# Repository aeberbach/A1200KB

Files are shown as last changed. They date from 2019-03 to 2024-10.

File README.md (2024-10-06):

# A1200KB Mechanical keyboard for Amiga A1200

As of right now this is revision 4. I know it could be improved very, very slightly by changing the position of key groups by less than a millimetre but I think it's complete now. 

This PCB design was reverse-engineered from the original keyboard in an Amiga 1200. It is designed to connect to your Amiga 1200 with no modifications to the original machine, just take out the original keyboard and store it away safely. If you want an A600 keyboard, see my other repositories.

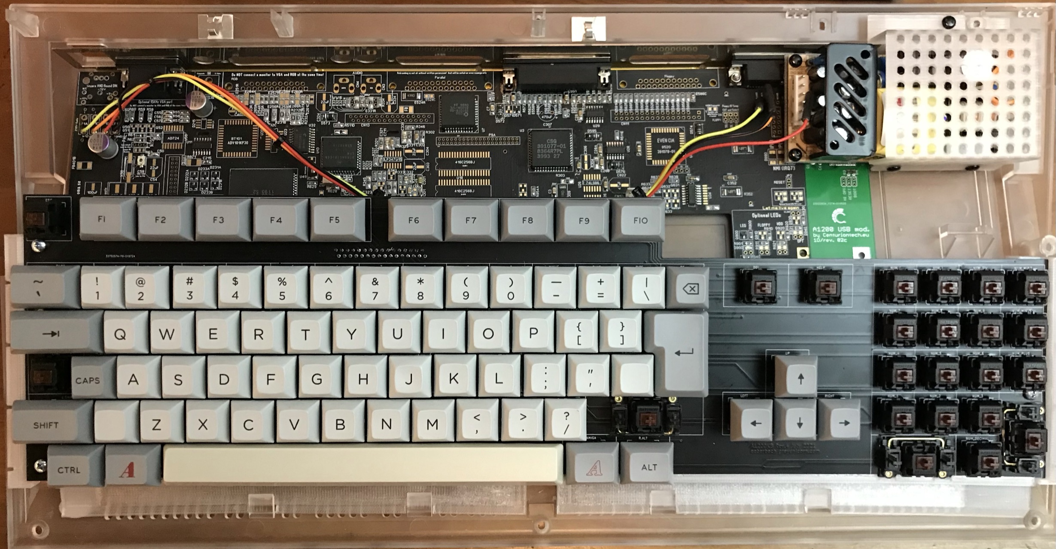
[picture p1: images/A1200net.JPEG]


The A1200.net case (with internal PSU and partially-completed [ReAmiga](http://www.reamiga.info/) board)

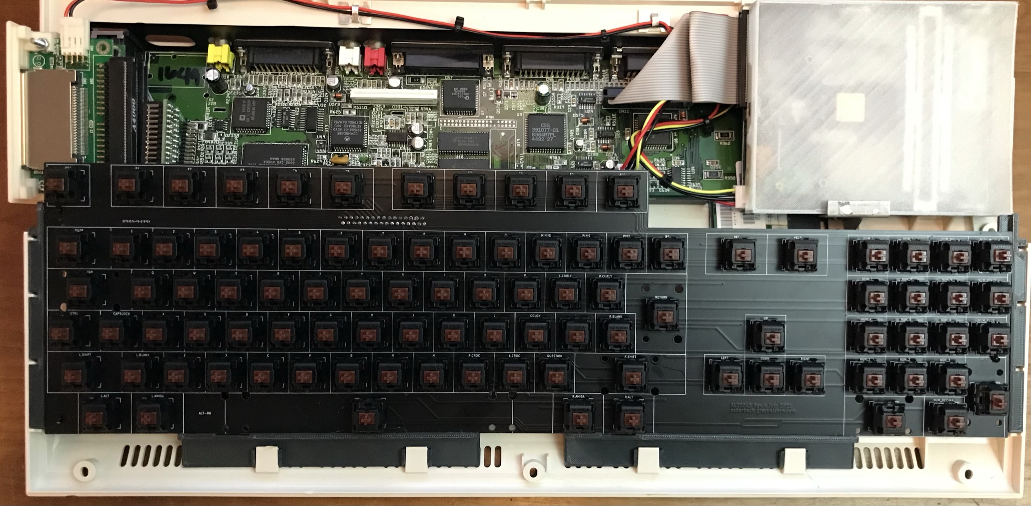
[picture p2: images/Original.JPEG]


The original Amiga case (with CF disk system and transparent floppy cover)

## Requirements
To make a working keyboard for your Amiga 1200, you need:

- one PCB (this project)
- 96 pieces MX-compatible PCB-mount (5-pin) keyswitch
- one LED (caps lock)
- one FFC connector, 32-way RA 1.25mm pitch. Molex 52044-3245 is one example, available from Mouser Electronics.
- one FFC ribbon cable, 32-way, 1.25mm pitch. Molex 15168-0400 is one example, available from Mouser Electronics.
- keycaps
- some way to mount the keyboard inside the Amiga (3D print some brackets from the STL folder...)
 
## Design
The Amiga 1200 keyboard is a simple passive key matrix connected via a 31-conductor cable. Some special keys are not on the matrix but have a dedicated circuit, such as the CTRL and Amiga keys - this is why so many conductors are necessary. The original Amiga 1200 PCB uses a 31-way FFC connector, I was not able to buy this anywhere as they are long discontinued. However cutting one conductor away from the cable allows it to fit in the Amiga connector with 31 conductors and to the keyboard with 32 conductors and everything is fine. The specified FFC cable is slightly longer than required but in 2019 there is not  a lot of choice available, so the longer one will do. 
I had my boards made with 1.6mm PCB substrate as any other thickness gets disproportionally expensive, no other special options. Using a piece of aluminium rail, 10x3mm, will make it as stiff as a keyboard should be while maintaining enough space underneath for an accelerator or Indivision etc. This is supported either side by the 3D printed mounts. Cover the aluminium with some kapton or other insulation if you have other internal components that may come dangerously close but in a stock Amiga there is plenty of clearance.

### Amiga Keycaps
These aren't widely available. I've tried making some using a blank set of keycaps from aliexpress and a laser etcher, but I do not know of anywhere that sells a MX-stem set of Amiga keycaps. I am using a 9U space bar but you can just as easily use 7U. If gaps either side of the space bother you, 3D print something to fill the space.

If you want a perfect set of keys, visit pimpmykeyboard.com - it will not be cheap but if you look hard enough you will find every key, even the Amiga keys, and you can have any legend printed on any size keycap so it is possible to make a perfect set. It will not be cheap. You can se a partial sample in the A1200.net picture. I am currently waiting for the extra numpad keys to arrive to complete this keyboard.

## Construction
Without going into all the detail here - as there is lots of detail on www.grayunicorn.com - I rate this a mid-level project. There is no power, no delicate soldering, and nothing can really be inserted the wrong way. Mounting the keyboard requires 3D printing the files you will find in the 3Dfiles folder.

If you have a replacement case produced by A1200.net then pick that folder, else the other folder. I don't know about cases made by ESCOM but I don't think they are at all different from the Commodore cases. I printed these in PETG, 0.4mm nozzle, 0.2mm layer height, supports are necessary. Mounting the keyboard with these designs allows the use of an accelerator card with a thick SIMM; I may design alternates if I get a slimmer accelerator, bringing the keys further back into the case but there is not much room.
 
You can damage your Amiga if you don't know what you are doing. Please be careful and if you are not experienced in projects like this get some help, maybe vist your local makerspace, and don't hurt yourself or your computer.

## Share
Most of all - if you have any suggestions for improvements, adding an issue or a pull request to this repo would be much appreciated. And share your project with the Amiga community, I'd really like to see what you made.

#### Donate?
I hate to think what this has cost so far. It's been fun and I'd do it again, but if you'd like to help the next project happen that would be awesome.



Note this this project is licensed under CC BY-NC-SA 4.0 - only noncommercial use is permitted! (By all means sell the excess PCBs you get, at cost, if you order some for your own use)

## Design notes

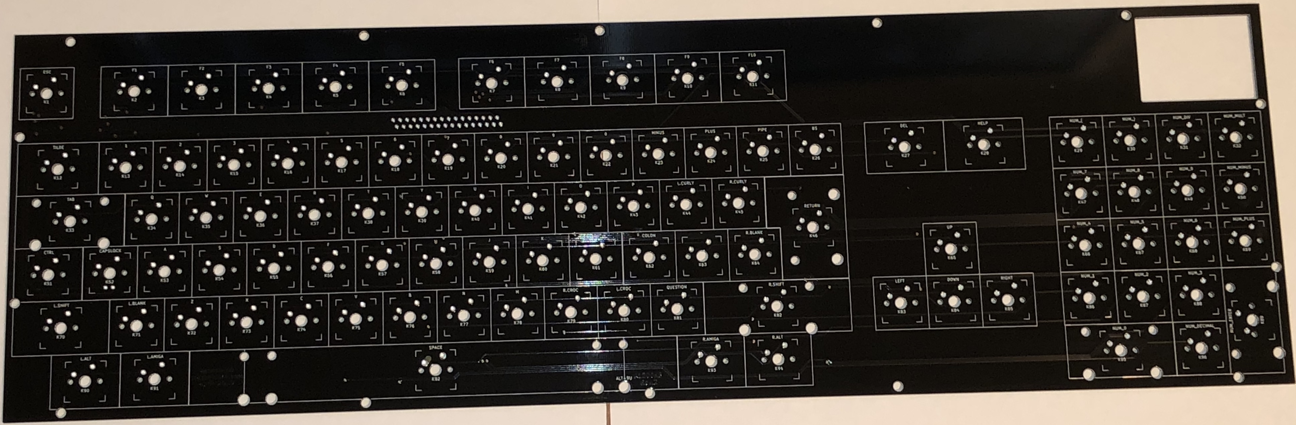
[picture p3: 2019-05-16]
images/rev2-pcb.jpg

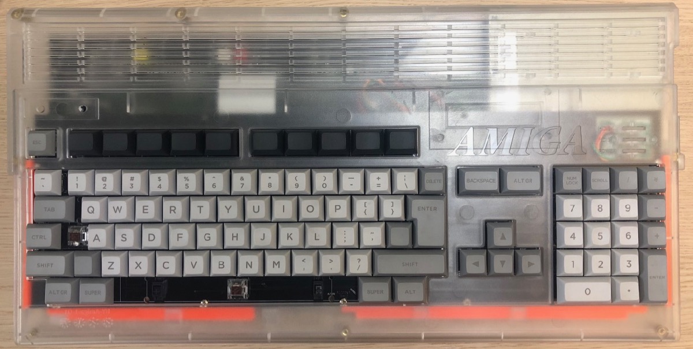
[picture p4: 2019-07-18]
images/case-closed.jpg

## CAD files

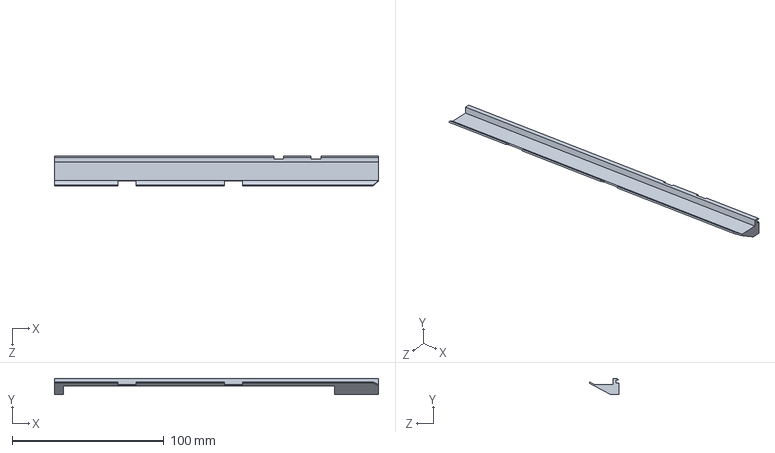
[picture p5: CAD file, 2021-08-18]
3Dfiles/A1200.net case/rev4/Right base.SLDPRT
213.5 x 10.6 x 19.5 mm

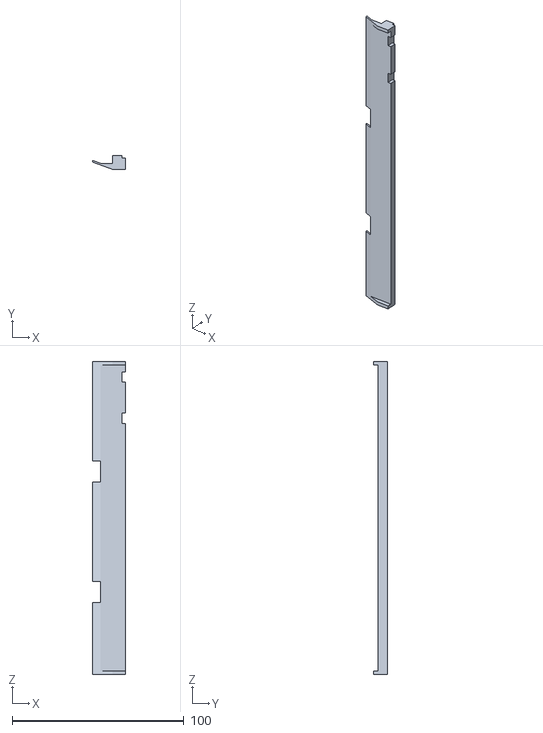
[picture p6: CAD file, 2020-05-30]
3Dfiles/A1200.net case/Right base support.stl
19.2 x 8.05 x 182.0

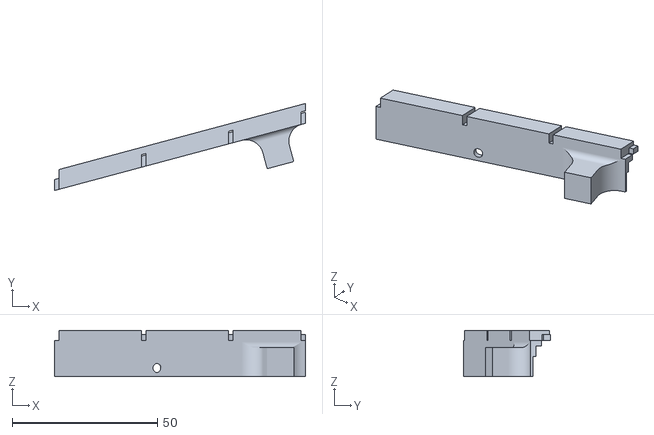
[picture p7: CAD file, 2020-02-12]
3Dfiles/Original Amiga case/Keyboard support right r2.stl
86.5 x 30.0 x 16.0

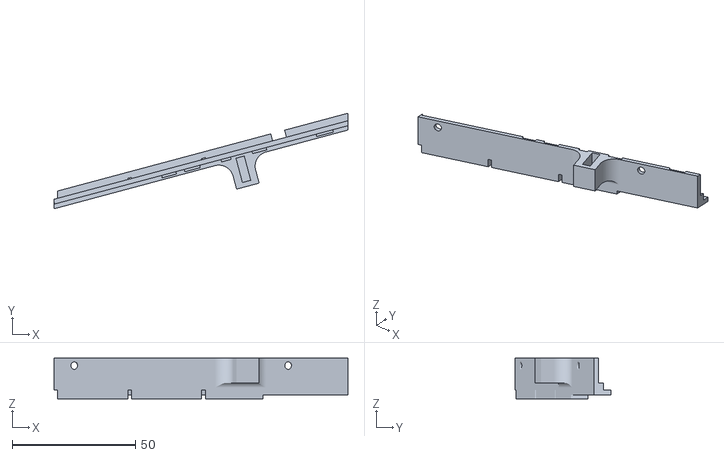
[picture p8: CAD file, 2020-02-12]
3Dfiles/Original Amiga case/rev2+3/Keyboard support left r2.stl
119.5 x 38.9 x 16.5

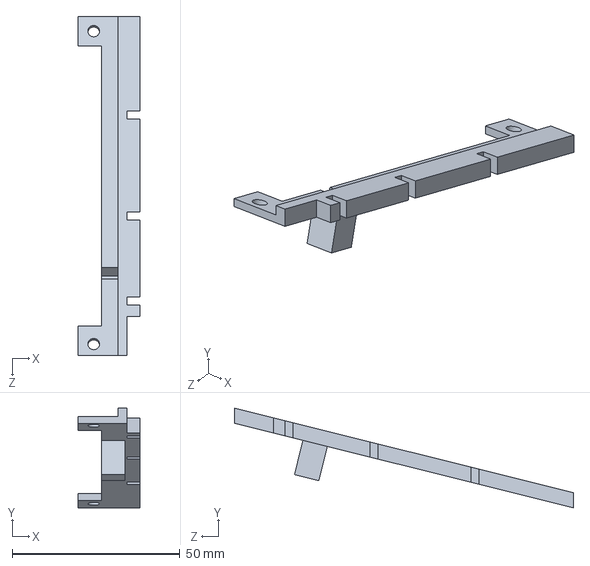
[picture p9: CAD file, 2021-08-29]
3Dfiles/Original Amiga case/rev4/Left side.SLDPRT
18.6 x 29.7 x 100.9 mm

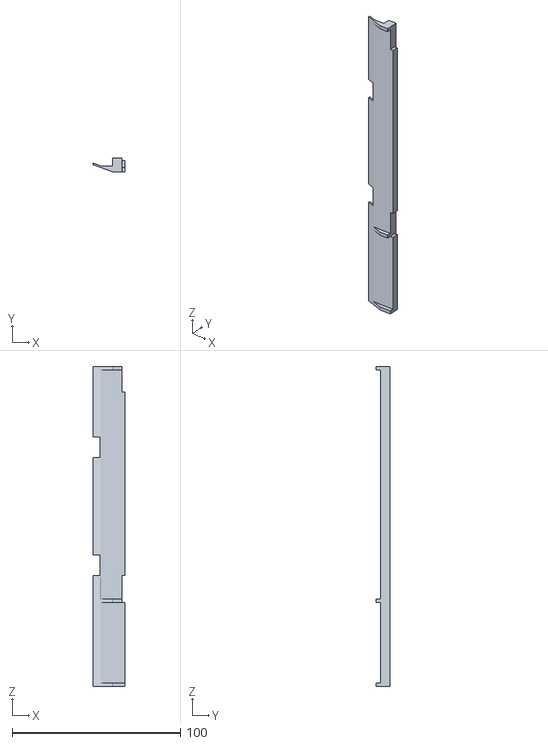
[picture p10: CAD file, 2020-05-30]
3Dfiles/A1200.net case/Left base support.stl
19.2 x 8.05 x 190.0

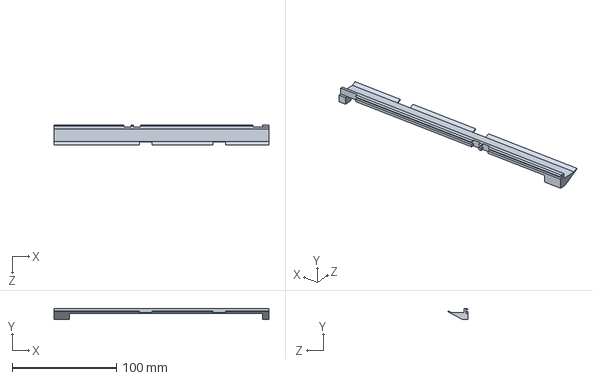
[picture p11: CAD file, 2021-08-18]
3Dfiles/A1200.net case/rev4/Left base.SLDPRT
206.0 x 10.6 x 19.5 mm

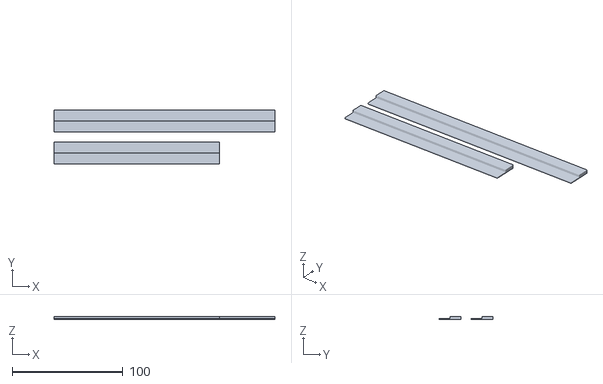
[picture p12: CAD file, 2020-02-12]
3Dfiles/Original Amiga case/kb base.stl
200.0 x 49.0 x 3.00

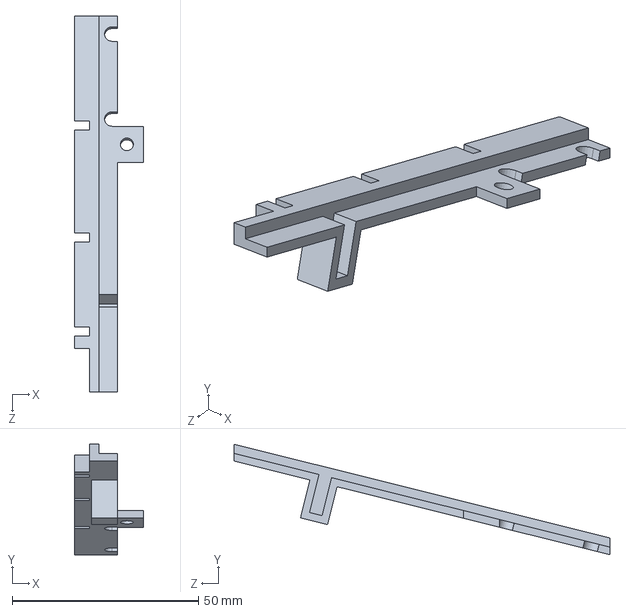
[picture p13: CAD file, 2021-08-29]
3Dfiles/Original Amiga case/rev4/Right side.SLDPRT
18.6 x 29.7 x 100.9 mm

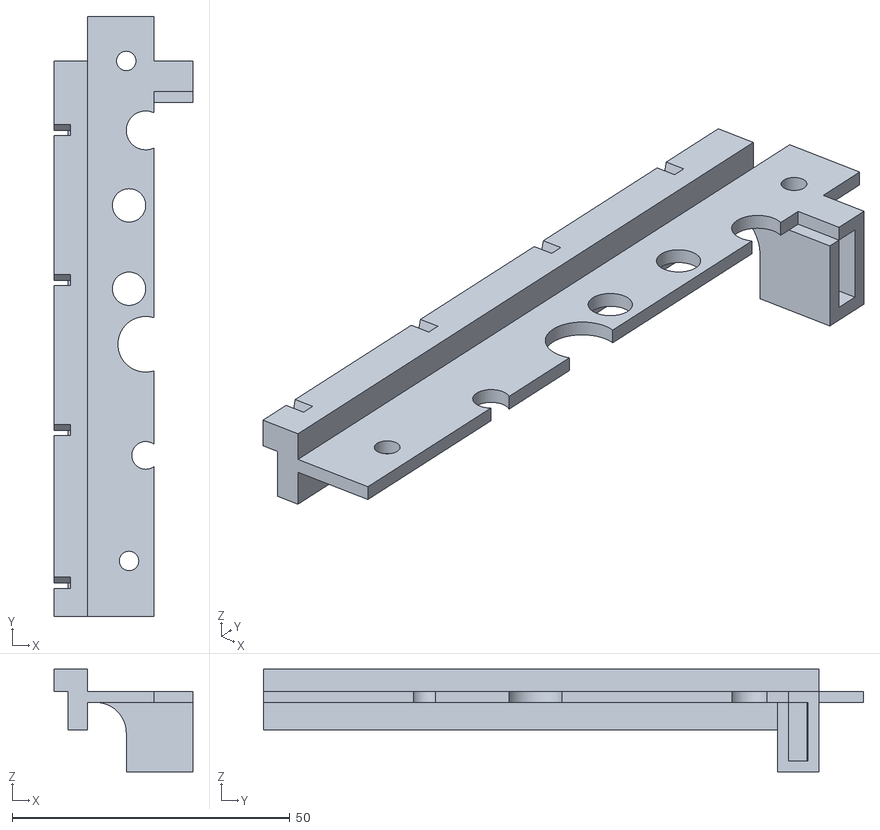
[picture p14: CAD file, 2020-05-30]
3Dfiles/A1200.net case/Left side.stl
25.0 x 108.0 x 18.5

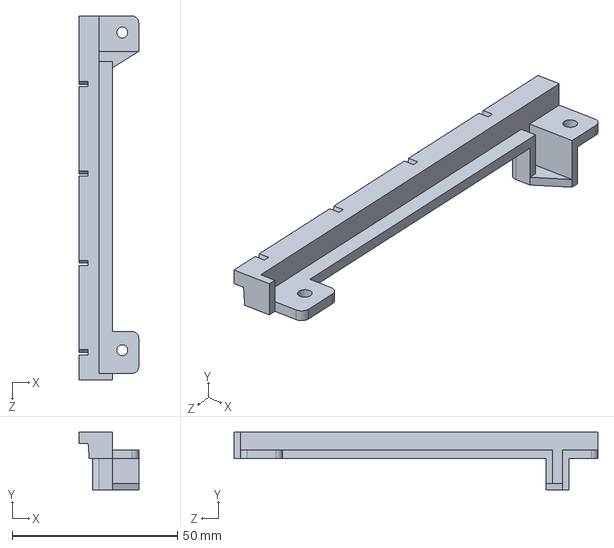
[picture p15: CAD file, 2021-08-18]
3Dfiles/A1200.net case/rev4/Left side.SLDPRT
18.0 x 17.5 x 110.0 mm

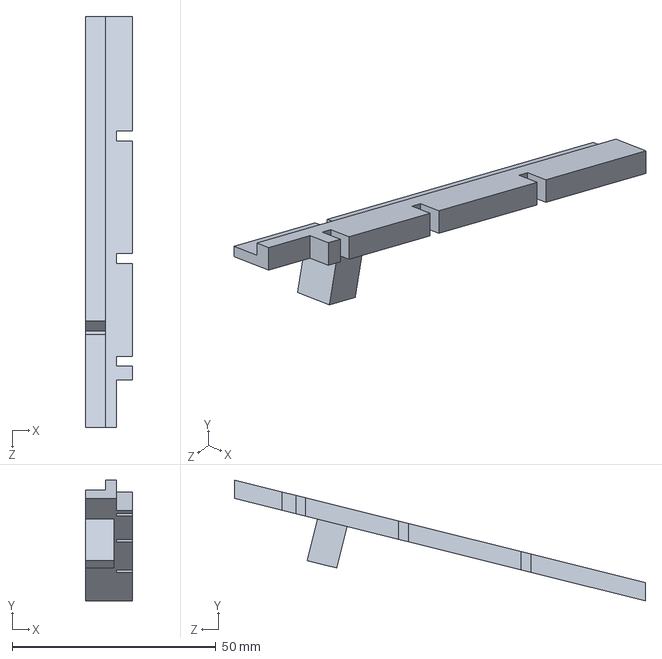
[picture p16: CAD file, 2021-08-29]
3Dfiles/Original Amiga case/rev4/Left side (for mirror).SLDPRT
11.6 x 29.7 x 100.9 mm

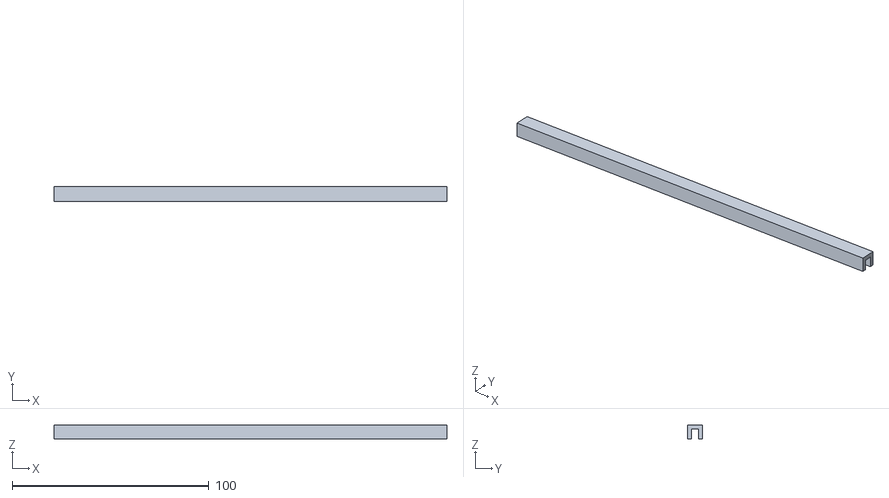
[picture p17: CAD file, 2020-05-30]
3Dfiles/A1200.net case/Brace insulator and spacer.stl
200.0 x 7.50 x 7.00

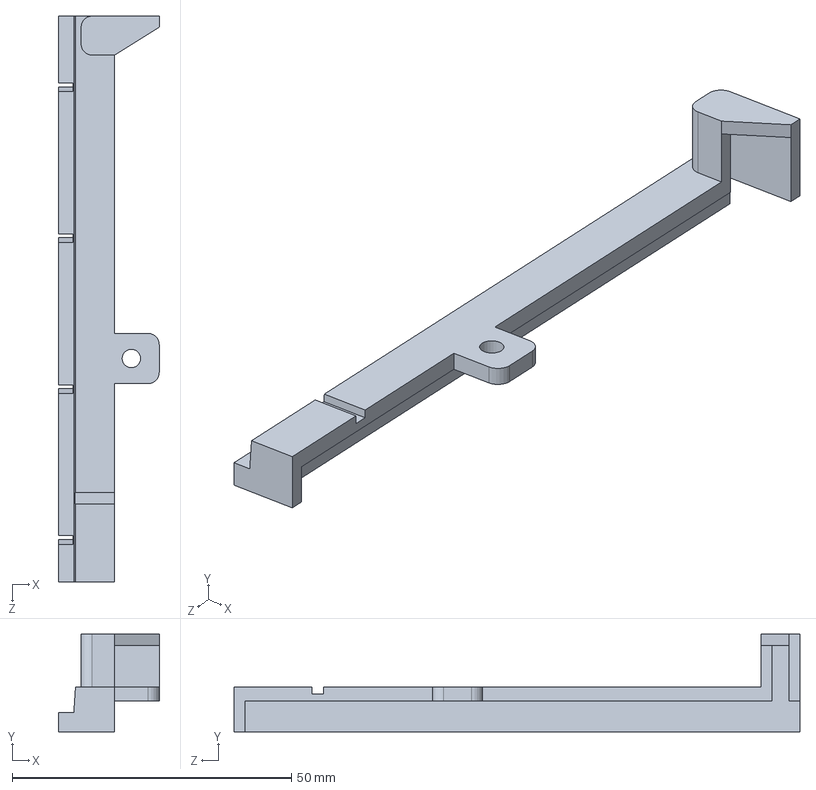
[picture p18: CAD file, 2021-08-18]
3Dfiles/A1200.net case/rev4/Right side.SLDPRT
18.0 x 17.5 x 101.3 mm

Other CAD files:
3Dfiles/Original Amiga case/rev4/Base.SLDPRT
3Dfiles/A1200.net case/Right side.stl
3Dfiles/A1200.net case/rev3/Right side.stl
3Dfiles/A1200.net case/rev4/Left base.STL
3Dfiles/A1200.net case/rev4/Left side.STL
3Dfiles/A1200.net case/rev4/Right base.STL
3Dfiles/A1200.net case/rev4/Right side.STL
3Dfiles/Original Amiga case/rev4/Base.STL
3Dfiles/Original Amiga case/rev4/Left side.STL
3Dfiles/Original Amiga case/rev4/Left side/Left side.ipt
3Dfiles/Original Amiga case/rev4/Right side.STL

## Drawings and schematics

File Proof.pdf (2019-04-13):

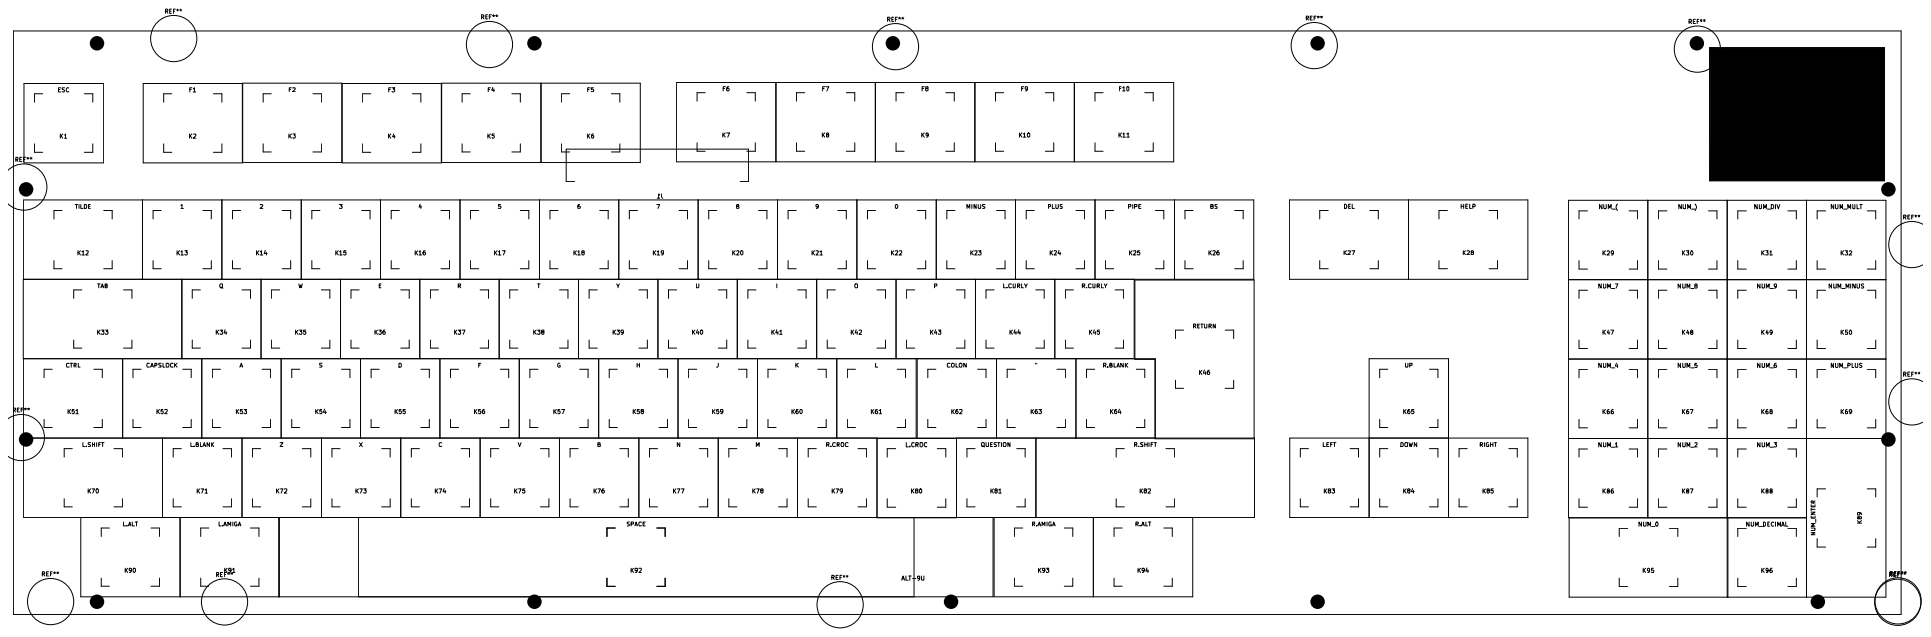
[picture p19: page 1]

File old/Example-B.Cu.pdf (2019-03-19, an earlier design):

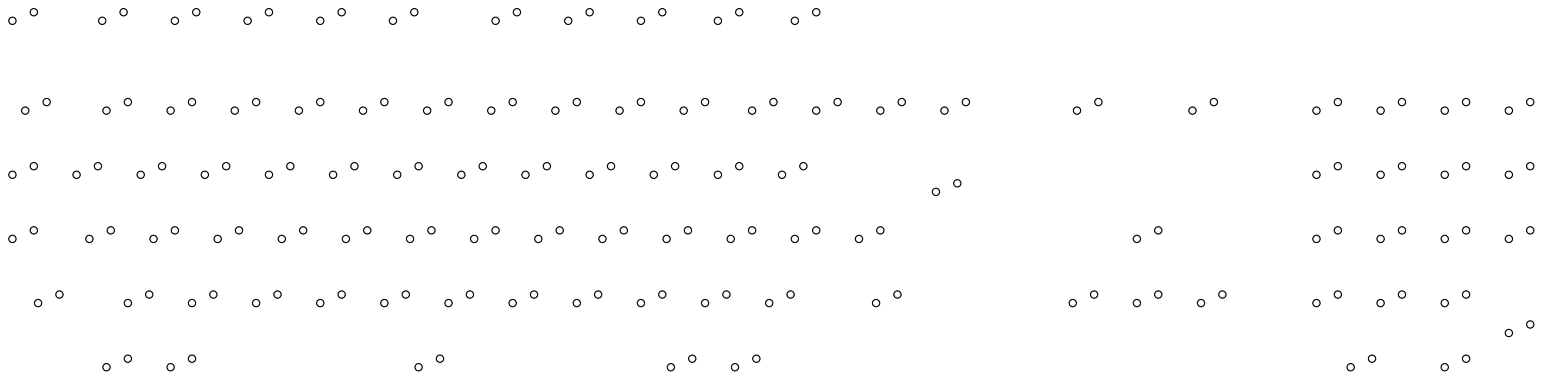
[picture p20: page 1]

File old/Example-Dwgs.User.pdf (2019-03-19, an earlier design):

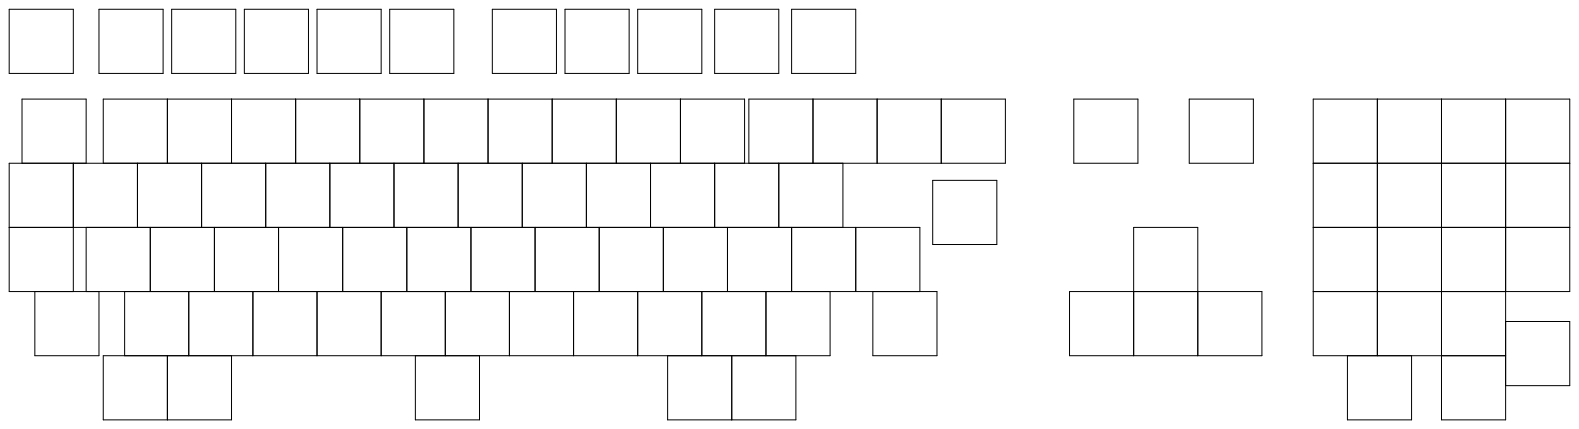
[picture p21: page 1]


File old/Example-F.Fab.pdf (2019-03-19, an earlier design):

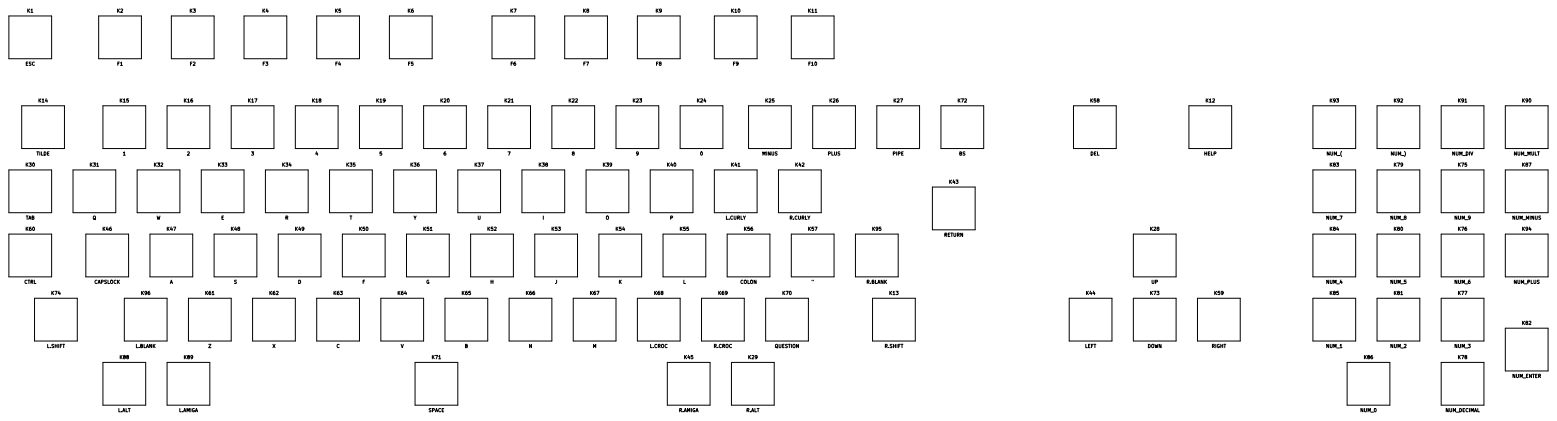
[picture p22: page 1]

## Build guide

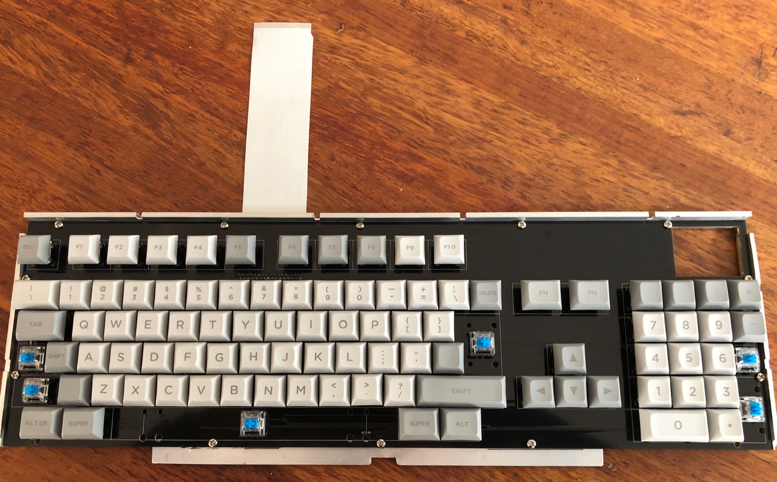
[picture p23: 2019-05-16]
images/soldered.jpg

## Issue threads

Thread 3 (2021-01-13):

Error Message when loading footprints

spacemishka, 2021-01-13:
Hello,

i got this error message when i tried "Assign Footprints"

```
Errors were encountered loading footprints:
Footprint library path "/Users/adam/Projects/MX_Alps_Hybrid.pretty" does not exist
```
Can you may add this library?

thanks!

aeberbach, 2022-01-16:
I have a clean PC install here and after installing KiCAD and syncing only this project I saw the same error. The library it is trying to load can be found at https://github.com/ai03-2725/MX_Alps_Hybrid. I highly recommend cloning a local copy and adding it to your KiCAD library. I prefer not to add a local copy to this repo as it works without and you may be better off making it useful as your own library for all projects not just this one.

Closed 2022-01-16.

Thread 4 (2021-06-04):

KMK/QMK based design (feature request)

oemsysadm, 2021-06-04:
There are various teased products out there, from replacement keyboards (like the kipper2k), to usb converters like the keyrah, but most of it seems like vaporware or at best is almost impossible to get a hold of.

For those of us who are interested in building emulators or FPGA based systems in a new A1200 case from A1200.net, there aren't many options for keyboards out there.

That said, DIY mechanical keyboards are relatively easy to do, but most of us don't have the knowledge to create a PCB; especially if it needs to conform to an existing design that a lot of us don't have access to directly measure.

How simple would it be to convert your existing PCB design to create something with a simpler column/row matrix that can easily be connected to a cheap micro controller flashed with one of the common keyboard firmwares, like KMK or QMK?

As an aside, what profile key caps did you use for the keyboard you have pictures of in this repository? It looks like DSA or something like that. I would assume not all key cap profiles will work for this.

aeberbach, 2022-01-06:
I did use DSA caps, just because they are my favourite and I could put together a complete set at Signature Plastics. Any MX-compatible set should be fine including OEM (most common) and SA.

I don't know exactly how hard it would be to make this a KMK/QMK design. This is a reverse-engineered reproduction of the original C= product and it relies on the Amiga's onboard keyboard decoder to interpret the 31 signals from the keyboard. That said, the connections are basically a matrix with horizontal and vertical rows with dedicated lines for about seven of the keys such as CTRL, Amiga, ALT etc. I have not done anything with that controller though...

Closed 2022-01-06.

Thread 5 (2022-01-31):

Wrong direction of Caps Lock switch / LED

OleUrgast, 2022-01-31:
Hello,
same as for the A600 kb, also the A1200 has the caps lock led on the right top. So the light from the led mounted at the bottom of the switch does not get to the window. The LED has to be at the top, so the switch has to be rotated 180°.
As the most simple way to make cherry keycaps is to use Amiga keycaps, cut the stem out and glue a cherry repair stem in (https://www.thingiverse.com/thing:1756671) on the A1200 it seems even more relevant than on the A600 (as it is more easy to source an old A500/A2000/A3000/A4000 for keycaps than an A600 due to the numbers sold)

aeberbach, 2022-11-27:
Good thought, if I revise this again I may flip all the keyswitches around for this reason (or would be happy to take a PR). For the capslock key I gave up trying to find a windowed keycap that looked good and just reply on the red glow around the key itself to show status.

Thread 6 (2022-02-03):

Error in soldering mask

OleUrgast, 2022-02-03:
Hello,
ordering the A1200kb PCB from pcbway yesterday they hinted an error in soldering mask:

"  About your order ,as the attache dpic showed, the pointed solderask openings at top side will expose the traces, pls advise if you can accept that and produce as your file?
Looking forward to your reply."
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

Of course this is not a big issue, so I confimed to produce the PCB as uploaded. But you might correct the solder mask in future revisions.

skielek, 2022-02-09:
Yea those are mistakes on the space and return keys, you dont want to expose the copper there or anywhere on the front. In fact, the switch footprints already have the necessary stencil mask, so there's no need that I see for any additional customisation of openings in the soldermask (front or back).

aeberbach, 2022-11-27:
This is an issue with the key library. Not ideal but functionally does not matter.

Closed 2022-11-27.

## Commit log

2019-03-19 The new PCB
    [A1200KB.kicad_pcb, A1200KB.sch]
2019-03-20 Placed all
    [A1200KB.kicad_pcb, A1200KB.sch]
2019-03-21 Layout complete and art to ourpcb
    [A1200KB-B_Cu.gbr, A1200KB-B_Mask.gbr, A1200KB-Dwgs_User.gbr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]
2019-04-13 Routed again, cutout for LED PCB, sized for Al supports
    [A1200KB.kicad_pcb]
2019-04-14 Submitted R2 to ourpcb
    [A1200KB-BACK_Cu.gbr, A1200KB-BACK_Mask.gbr, A1200KB-B_Cu.gbr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]
2019-05-16 add pcb image
2019-05-16 Printer note
2019-07-18 STL files, readme revised
    [Bottom support v2.stl, Side supports v5.stl, Support covers v3.stl]
2019-10-21 fixed bad route at return key
    [A1200KB.kicad_pcb]
2019-10-21 Renegerated mfg outputs
    [A1200KB-B_Cu.gbr, A1200KB-B_Mask.gbr, A1200KB-B_SilkS.gbr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]
2019-12-11 Rev 3!
    Board is smaller for more flexibility in mounting. Stabs are turned inwards. Traces moved to make fitting mounting holes easier. This will need a new 3D printed mounting solution…
    [A1200KB-B_Cu.gbr, A1200KB-B_Mask.gbr, A1200KB-B_SilkS.gbr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]
2020-02-12 Replace rev 2 3D support STL with rev 3
    [Bottom support v2.stl, Keyboard support left r2.stl, Keyboard support right r2.stl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]
2020-05-30 New 3D printed files for A1200.net case
    [Brace insulator and spacer.stl, Keyboard support left r2.stl, Keyboard support right r2.stl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]
2020-05-30 Fixed base support files
    [Left base support.stl, Right base support.stl]
2021-07-22 Begin rev4, organize 3D files
    [Brace insulator and spacer.stl, Keyboard support left r2.stl, Keyboard support right r2.stl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]
2021-08-18 Better alignment of key groups with each other
    More or less a perfect fit now. Also new mount STLs for A1200.net case. I'm getting around to redoing the Commodore case mounts soon.
    [A1200KB-B_Cu.gbr, A1200KB-B_Mask.gbr, A1200KB-Edge_Cuts.gbr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]
2021-08-29 Rev 4 complete
    [Base.SLDPRT, Base.STL, Left side (for mirror).SLDPRT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]
2024-06-30 Open with KiCAD 8
2024-10-06 last revision
    [Left side.ipt]
